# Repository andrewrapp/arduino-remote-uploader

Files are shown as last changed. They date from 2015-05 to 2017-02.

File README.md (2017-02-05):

# arduino-remote-uploader

The goal of this project is provide over-the-air (OTA) upload of Arduino sketches to a remote Arduino. There is support for XBee (Series 1 and 2), Wifi (ESP8266), and Nordic nRF24L01+. This is accomplished by programming one Arduino with another. The circuit is conceptually very simple:

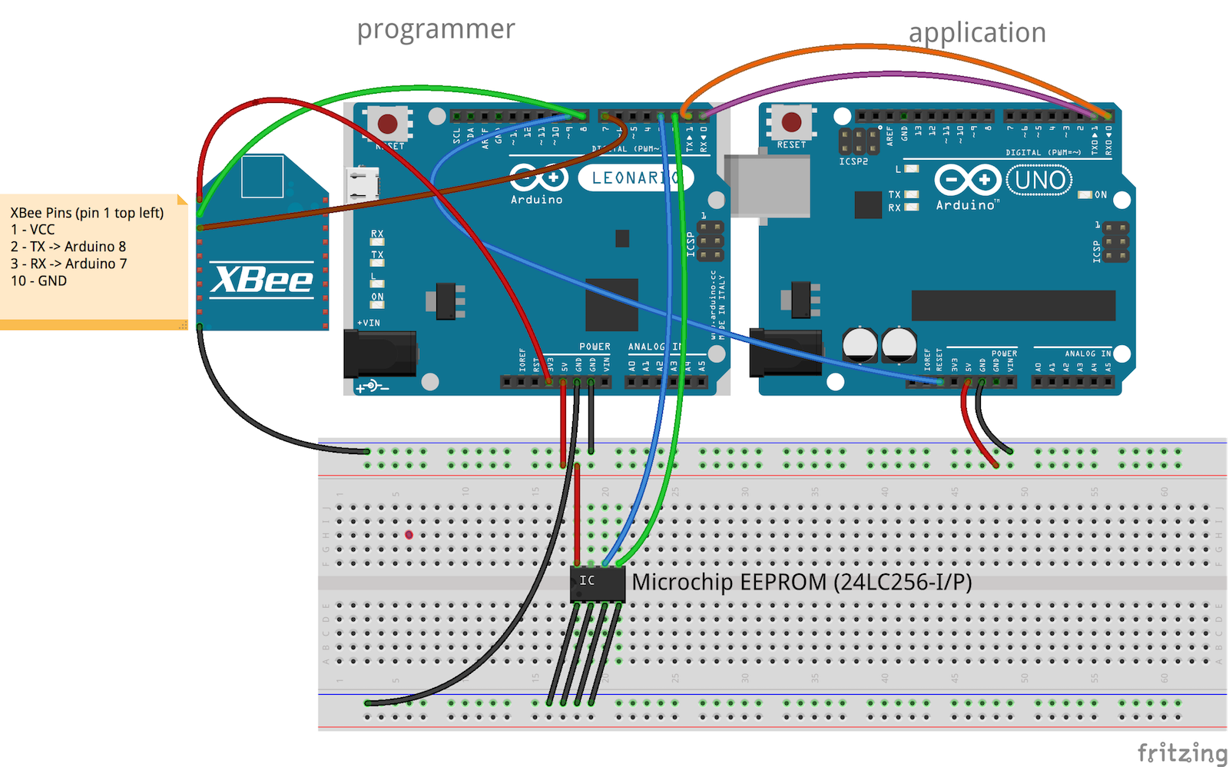
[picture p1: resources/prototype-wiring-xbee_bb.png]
xbee prototype


One Arduino receives firmware packets from a wireless device (XBee in this case) and writes to EEPROM. Then, once it receives the entire sketch it flashes the firmware on the other Arduino. There are other tricks for remote firmware programming but nearly all involve unfortunate tradeoffs. This solution is fault tolerant, in that it checksums every firmware page (packet), acks and retries dropped packets and only flashes when a complete firmware image has been written to EEPROM. You can unplug the remote during programming, then plug back in and it will resume and flash successfully.

It's also quite cost-effective: the Microchip EEPROM costs $1. Arduino Pros can be found online for about $3 each. Nordic radios can be found for about $1 online.

Here's a prototype I built to control my garage door. A Modern Device RBBB performs the programming while the app runs on a Arduino Pro. I'm using an Arduino XBee shield just for the XBee socket and 3.3V conversion. 

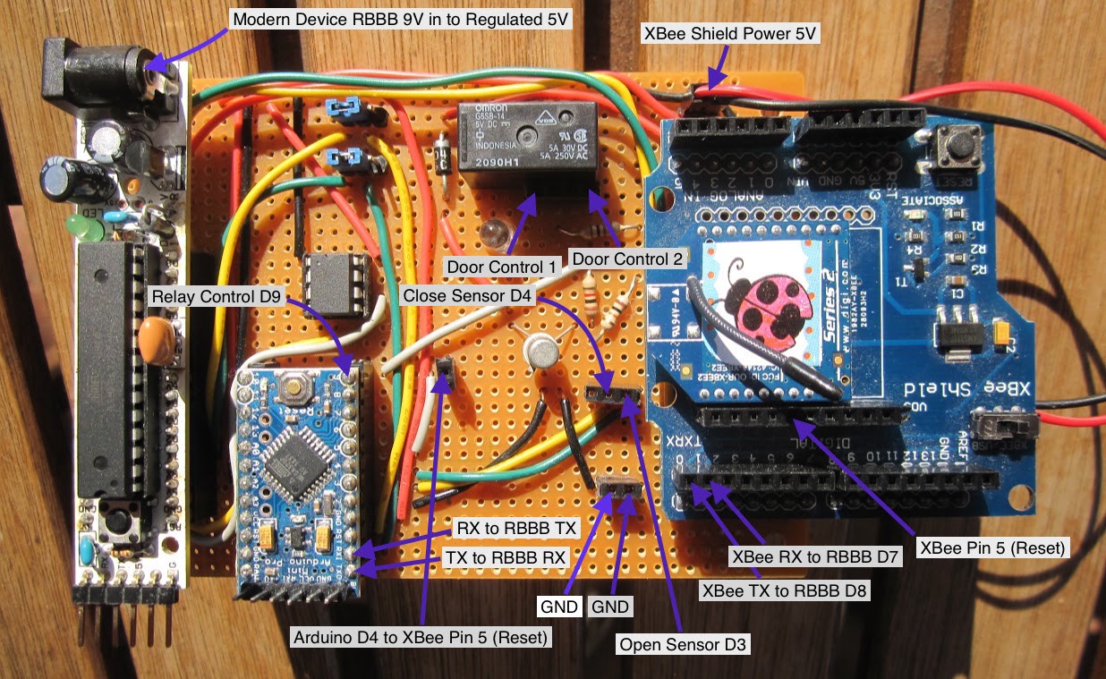
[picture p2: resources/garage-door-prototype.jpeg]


The client is a simple command-line app:

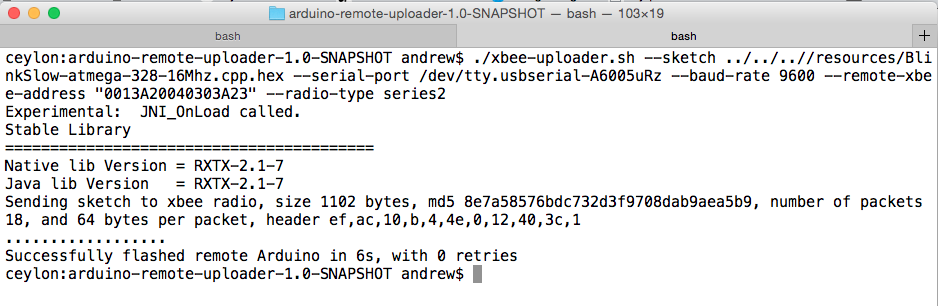
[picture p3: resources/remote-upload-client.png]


Here's a <a href="https://youtu.be/Vqg-zZniQU0" target="_blank">screenshare</a> of an upload in action.

Version [0.1](https://search.maven.org/#search%7Cga%7C1%7Ca%3A%22arduino-remote-uploader%22) is in Maven Central

<!--<video src="https://github.com/andrewrapp/arduino-remote-uploader/blob/master/resources/remote-flash-screen-recording.mov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" controls autoplay></video>-->

I've written about the project in detail on Medium https://medium.com/@nowir3s/arduino-remote-uploader-aa61e4d620b1

Demo

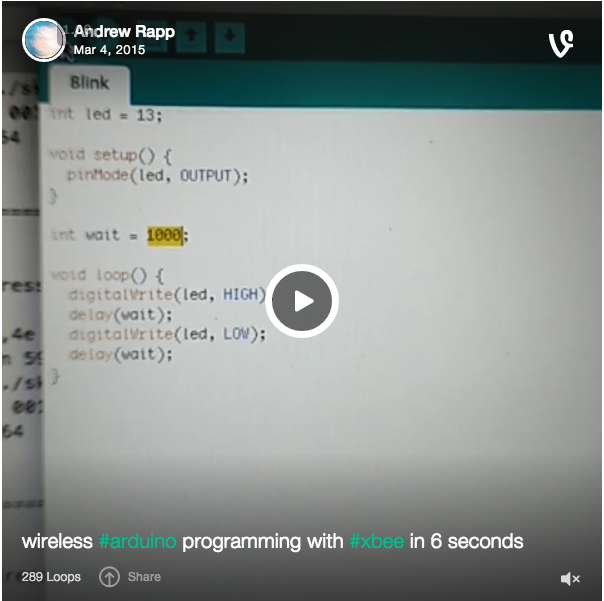
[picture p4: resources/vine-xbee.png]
vine


The remote Arduino starts with a sketch that blinks fast. Then, I change the sketch to blink slow, compile and flash the sketch on the remote Arduino, via XBee. The command completes and indicates that the flash was successful. And lastly we see the Arduino is running the new sketch and blinking slowly. So there it is: over-the-air Arduino programming via XBee in six seconds!

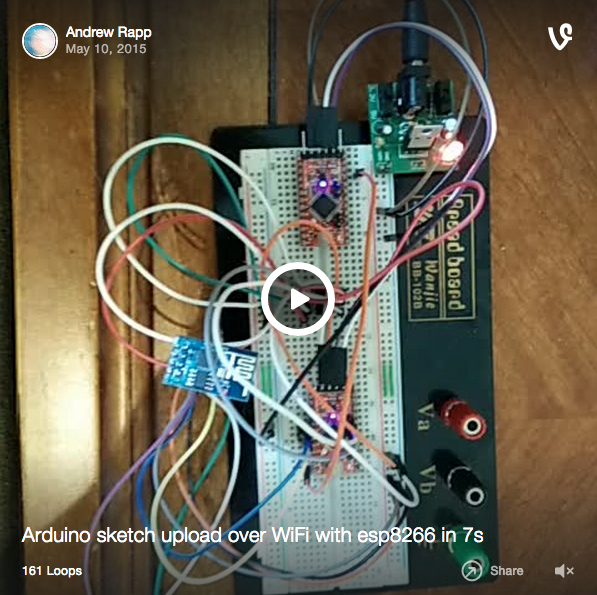
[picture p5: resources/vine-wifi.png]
vine


Here's the same thing but over wifi with a esp8266 and 3.3V Arduino Pros at 8Mhz.

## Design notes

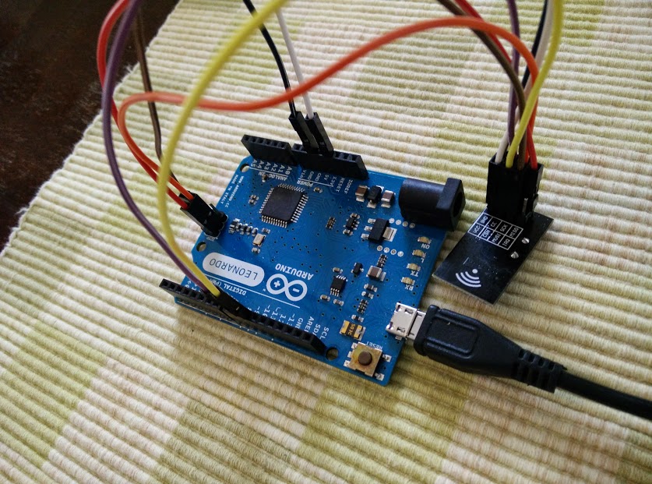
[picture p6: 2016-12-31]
resources/nordic-arduino.jpg

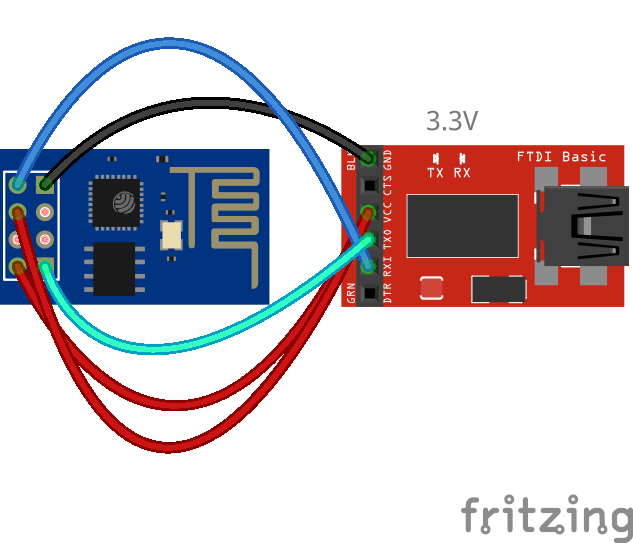
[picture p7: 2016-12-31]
resources/esp8266-ftdi_bb.png

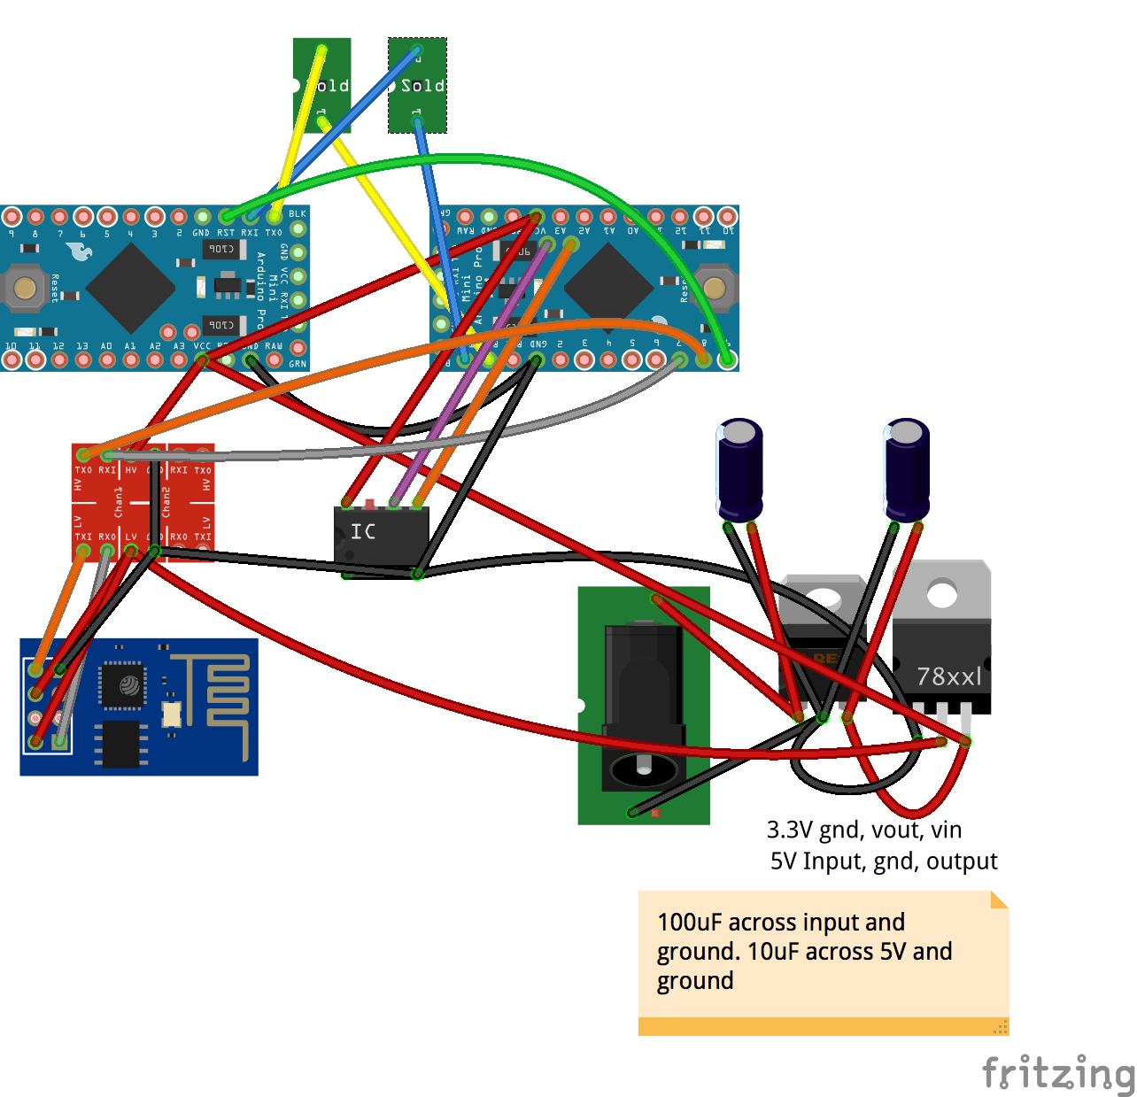
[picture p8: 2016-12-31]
resources/esp-perfboard_bb.png

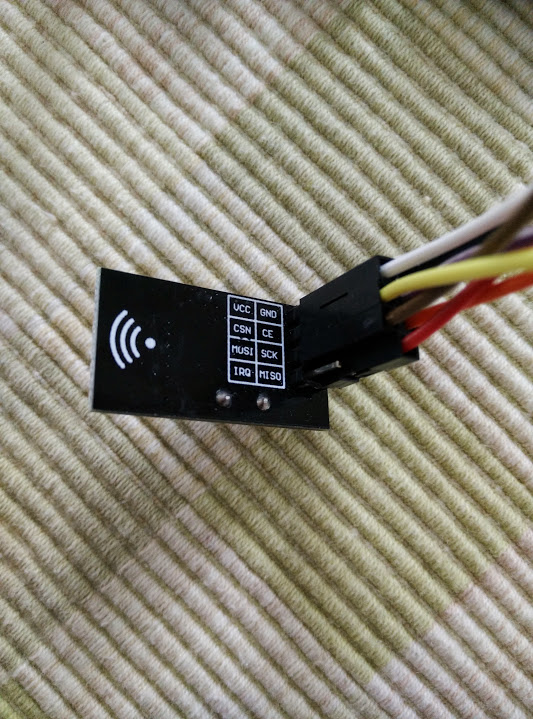
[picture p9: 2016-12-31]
resources/nordic-pins.jpg

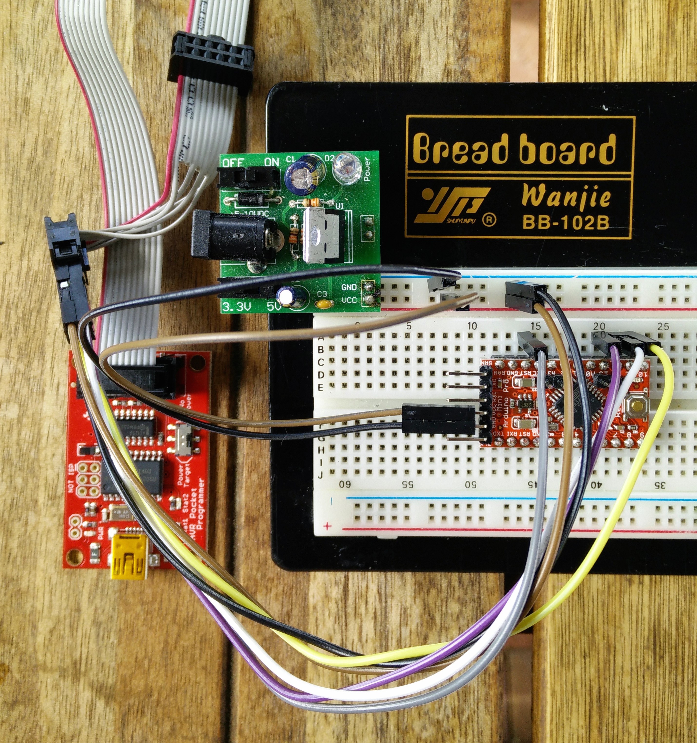
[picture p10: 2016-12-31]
resources/pocketprogrammer-arduino-pro.jpg

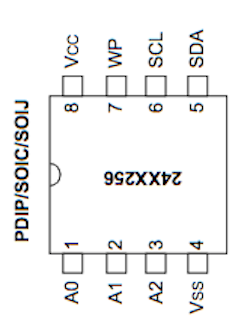
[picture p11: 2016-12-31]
resources/microchip-eeprom-pins.png

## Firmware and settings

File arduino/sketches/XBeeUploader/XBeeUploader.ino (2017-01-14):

/**
 * Copyright (c) 2015 Andrew Rapp. All rights reserved.
 *
 * This file is part of arduino-sketcher
 *
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
 * You should have received a copy of the GNU General Public License
 * along with arduino-sketcher.  If not, see <http://www.gnu.org/licenses/>.
 */
 
#include <XBee.h>
#include <SoftwareSerial.h>
#include <extEEPROM.h>
#include <Wire.h>
#include <RemoteUploader.h>

// NOTE: Leonardo seems to have no problem powering the xbee ~50ma and and a Diecimila

// If the xbee is only used for firmware updates and the app arduino doesn't use it this can be false
#define PROXY_SERIAL true
#define XBEE_BAUD_RATE 9600
#define USBDEBUG false

#define SERIES1 1
#define SERIES2 2

// TODO send with start header
#define ACK_TIMEOUT 1000

// these can be swapped to any other free digital pins
#define XBEE_SOFTSERIAL_RX_PIN 7
#define XBEE_SOFTSERIAL_TX_PIN 8
#define RESET_PIN 9

// set a dummy address. all tx will be sent to the sender via getRemoteAddress
const uint32_t COORD_MSB_ADDRESS = 0;
const uint32_t COORD_LSB_ADDRESS = 0;

XBee xbee = XBee();
XBeeResponse response = XBeeResponse();
// series 1 rx objects
Rx64Response rx1 = Rx64Response();
// series 2
ZBRxResponse rx2 = ZBRxResponse();

// format magic bytes, status, id1, id2
uint8_t xbeeTxPayload[] = { MAGIC_BYTE1, MAGIC_BYTE2, 0, 0, 0 };

// TODO use ifdef to either include series 1 or 2 but not both

// Coordinator Gateway
XBeeAddress64 addr64 = XBeeAddress64(COORD_MSB_ADDRESS, COORD_LSB_ADDRESS);
// series 1
Tx64Request tx1 = Tx64Request(addr64, xbeeTxPayload, sizeof(xbeeTxPayload));
// series 2
ZBTxRequest tx2 = ZBTxRequest(addr64, xbeeTxPayload, sizeof(xbeeTxPayload));

// status response
// series 1
TxStatusResponse txStatus1 = TxStatusResponse();
// series 2
ZBTxStatusResponse txStatus2 = ZBTxStatusResponse();

//Since Arduino 1.0 we have the superior softserial implementation: NewSoftSerial
// Remember to connect all devices to a common Ground: XBee, Arduino and USB-Serial device
SoftwareSerial nss(XBEE_SOFTSERIAL_TX_PIN, XBEE_SOFTSERIAL_RX_PIN); // RX, TX

RemoteUploader remoteUploader = RemoteUploader();

extEEPROM eeprom = extEEPROM(kbits_256, 1, 64);

// keep track radio type: series 1 or 2
uint8_t series = 0;

Stream* getXBeeSerial() {
  return &nss;  
}

void setup() {
  // for atmega328/168 use &Serial
  // do not set baud rate as the uploader does this
  remoteUploader.setup(&Serial, &eeprom, RESET_PIN);  
  // for Leonardo must use Serial1
  //remoteUploader.setup(&Serial1, &eeprom, RESET_PIN);
  //configure debug if an additional Serial port is available. Use Serial with Leonardo
  // for some reason I can only program with a Leonardo when the serial console is open, even if I'm not using debug!
  //remoteUploader.setDebugSerial(&Serial);

  // TODO if setup_success != OK send error programming attempt
  // we only have one Serial port (UART) so need nss for XBee
  
  nss.begin(XBEE_BAUD_RATE);  
  xbee.setSerial(nss);

  // Start the serial port for the xbee baud rate when proxying
  if (PROXY_SERIAL) {
    // we flashed so reset to xbee baud rate for proxying
    remoteUploader.getProgrammerSerial()->begin(XBEE_BAUD_RATE);              
  }
            
  #if (USBDEBUG || NSSDEBUG) 
    remoteUploader.getDebugSerial()->println("Ready");
  #endif
}

// TODO move to library.. tell library of the proxySerial port
void handleProxy() {
  // don't need to test in_prog. if in prog we are just collecting packets so can keep relaying. when flashing, it's blocking so will never get here
  // forward packets from target out the radio
  if (PROXY_SERIAL) {
    while (remoteUploader.getProgrammerSerial()->available() > 0) {
      int b = remoteUploader.getProgrammerSerial()->read();
      getXBeeSerial()->write(b); 
    }      
  }
}

// TODO send version
int sendReply(uint8_t status, uint16_t id) {
  xbeeTxPayload[0] = MAGIC_BYTE1;
  xbeeTxPayload[1] = MAGIC_BYTE2;
  xbeeTxPayload[2] = status;
  xbeeTxPayload[3] = (id >> 8) & 0xff;
  xbeeTxPayload[4] = id & 0xff;
  
  // TODO send with magic packet host can differentiate between relayed packets and programming ACKS
  if (series == SERIES1) {
    xbee.send(tx1);        
  } else if (series == SERIES2) {
    // send reply to sender xbee
    tx2.setAddress64(rx2.getRemoteAddress64());
    xbee.send(tx2);    
  }
  
  // after send a tx request, we expect a status response
  // wait up to half second for the status response
  if (xbee.readPacket(ACK_TIMEOUT)) {    
    if (xbee.getResponse().getApiId() == ZB_TX_STATUS_RESPONSE) {
      // series 2
      xbee.getResponse().getZBTxStatusResponse(txStatus2);

      // get the delivery status, the fifth byte
      if (txStatus2.isSuccess()) {
        return 0;
      } else {
        #if (USBDEBUG || NSSDEBUG) 
          remoteUploader.getDebugSerial()->println("TX fail");
        #endif  
      }
    } else if (xbee.getResponse().getApiId() == TX_STATUS_RESPONSE) {
      // series 1
      xbee.getResponse().getTxStatusResponse(txStatus1);
        
      if (txStatus1.getStatus() == SUCCESS) {
        return 0;
      } else {
        #if (USBDEBUG || NSSDEBUG) 
          remoteUploader.getDebugSerial()->println("TX fail");
        #endif      
      }  
    }   
  } else if (xbee.getResponse().isError()) {
    #if (USBDEBUG || NSSDEBUG)
      // starting to see lots of these. check wire connections are secure
      remoteUploader.getDebugSerial()->print("TX error:");  
      remoteUploader.getDebugSerial()->print(xbee.getResponse().getErrorCode());
    #endif
  } else {
    #if (USBDEBUG || NSSDEBUG) 
      remoteUploader.getDebugSerial()->println("TX timeout");
    #endif  
  } 
  
  return -1;
}


// borrowed from xbee api. send bytes with proper escaping
void send_xbee_packet(uint8_t b, bool escape) {
  if (escape && (b == START_BYTE || b == ESCAPE || b == XON || b == XOFF)) {
    remoteUploader.getProgrammerSerial()->write(ESCAPE);    
    remoteUploader.getProgrammerSerial()->write(b ^ 0x20);
  } else {
    remoteUploader.getProgrammerSerial()->write(b);
  }
  
  remoteUploader.getProgrammerSerial()->flush();
}

void forwardPacket() {
  // not programming packet, so proxy all xbee traffic to Arduino
  // prob cleaner way to do this if I think about it some more
  
  #if (USBDEBUG || NSSDEBUG) 
    remoteUploader.getDebugSerial()->println("Forwarding packet");    
  #endif
        
  // send start byte, length, api, then frame data + checksum
  send_xbee_packet(START_BYTE, false);
  send_xbee_packet(xbee.getResponse().getMsbLength(), true);
  send_xbee_packet(xbee.getResponse().getLsbLength(), true);        
  send_xbee_packet(xbee.getResponse().getApiId(), true);

  uint8_t* frameData = xbee.getResponse().getFrameData();
   
  for (int i = 0; i < xbee.getResponse().getFrameDataLength(); i++) {
    send_xbee_packet(*(frameData + i), true);
  }
   
   send_xbee_packet(xbee.getResponse().getChecksum(), true);  
}

// TODO ack needs to send the id (packet #) otherwise we may be getting a different ack, right?

void loop() {        
  xbee.readPacket();
  
  if (xbee.getResponse().isAvailable()) {  
    // if not programming packet, relay exact bytes to the arduino. need to figure out how to get from library
    // NOTE the target sketch should ignore any programming packets it receives as that is an indication of a failed programming attempt
          
      uint8_t *packet = NULL;
      uint8_t length;
      bool progPacket = false;
      
      if (xbee.getResponse().getApiId() == ZB_RX_RESPONSE) {  
        // series 2    
        series = SERIES2;
        // now fill our zb rx class
        xbee.getResponse().getZBRxResponse(rx2);
        
        // pointer of data position in response
        packet = xbee.getResponse().getFrameData() + rx2.getDataOffset();
        length = rx2.getDataLength();
      } else if (xbee.getResponse().getApiId() == RX_64_RESPONSE) {
        // series 1
        series = SERIES1;        
        xbee.getResponse().getRx64Response(rx1);      

        // pointer of data position in response
        packet = xbee.getResponse().getFrameData() + rx1.getDataOffset();        
        length = rx1.getDataLength();
      } else {
        // unexpected packet.. ignore
      }

      if (packet != NULL) {
        if (length > 4 && remoteUploader.isProgrammingPacket(packet, length)) {
          progPacket = true;
          
          // send the packet array, length to be processed
          int response = remoteUploader.process(packet);
              
          // do reset in library
          if (response != OK) {
            remoteUploader.reset();
          }

          sendReply(response, remoteUploader.getPacketId(packet));          
          
          if (remoteUploader.isFlashPacket(packet)) {
            if (PROXY_SERIAL) {
              // we flashed so reset to xbee baud rate for proxying
              remoteUploader.getProgrammerSerial()->begin(XBEE_BAUD_RATE);              
            }
          }          
        }     
      }
      
      if (!progPacket && PROXY_SERIAL) {
        // not a programming packet. forward along
        forwardPacket();                           
      }
  } else if (xbee.getResponse().isError()) {
    #if (USBDEBUG || NSSDEBUG) 
      remoteUploader.getDebugSerial()->print("RX error: ");
      remoteUploader.getDebugSerial()->println(xbee.getResponse().getErrorCode(), DEC);
    #endif  
  }  
  
  handleProxy();
}

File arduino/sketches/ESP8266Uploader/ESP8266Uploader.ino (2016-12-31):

/**
 * Copyright (c) 2015 Andrew Rapp. All rights reserved.
 *
 * This file is part of arduino-sketcher
 *
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
 * You should have received a copy of the GNU General Public License
 * along with arduino-sketcher.  If not, see <http://www.gnu.org/licenses/>.
 */

#include <extEEPROM.h>
// eeprom requires i2c
#include <Wire.h>
#include <SPI.h>

#include <RemoteUploader.h>
#include <Esp8266.h>
#include <SoftwareSerial.h>

// NOTE: only some pins support softserial RX on Leonard and Mega boards
#define ESP_RX 8
#define ESP_TX 7

#define ESP_PACKET_SIZE 32

#define REPLY_SIZE 5
#define RESET_PIN 9

#define LED_PIN 13

// TODO send ip address to server on boot for discovery. Otherwise we'd have to guess or query the router's dhcp table (not always possible)

// FIXME client is getting socket timeouts. add ping method to restart if loses ip address
// TODO proxy when not in programming mode

// When true this only tests the ESP communication, does not use the remote uploader library.
// This is useful to debug any issues with ESP using the serial port before throwing flashing into the mix
#define COMMUNICATION_TEST false

SoftwareSerial espSerial(ESP_RX, ESP_TX);
Esp8266 esp8266 = Esp8266();

// this is arbitrary, any port will do
int serverPort = 1111;

uint8_t replyPayload[] = { MAGIC_BYTE1, MAGIC_BYTE2, 0, 0, 0 };
uint8_t packet[ESP_PACKET_SIZE];

RemoteUploader remoteUploader = RemoteUploader();
extEEPROM eeprom = extEEPROM(kbits_256, 1, 64);

/* 6/24 - at times getting ERROR or just an OK on listing networks (with FTDI). Also will not join a network. Could it be the access point rejecting?
AT+CWLAP

ERROR

AT+CWLAP

OK
*/

// 6/25 esp passes communication test on perfboard with DEBUG enabled, but once debug is set to false it gets an IPD error and sketch resets the radio
// setup works fine. Could be the voltage divider can't handle the speed without debug slowdown
// try leonardo with debug
// try 3.3V Arduinos

void setup() {
  
  pinMode(LED_PIN, OUTPUT);   
    
  if (COMMUNICATION_TEST == false) {
    // for Leonardo use &Serial1
    // for atmega328/168 use &Serial
    if (remoteUploader.setup(&Serial, &eeprom, RESET_PIN) != SUCCESS) {
      // eeprom fail
      // optional error reporting
      blink(2, 2000);
    }
    
    //configure debug if an additional Serial port is available (e.g. Leonardo)
    //remoteUploader.setDebugSerial(&Serial);    
    
    // NOTE: Only if you are using a 3.3V/8Mhz I highly recommend running Optiboot at 57.6K instead of 115.2K with 8Mhz Arduinos. This requires the 5V/16Mzh optiboot bootloader
    //remoteUploader.setBaudRate(OPTIBOOT_8MHZ_BAUD_RATE);
  }

  // delay is recommended since if esp8266 is booting it will spew the boot garbage for about 3 seconds. any setup commands would fail
  delay(3000);  
  
  espSerial.begin(9600);
  // configure esp to use softserial
  esp8266.setEspSerial(&espSerial);  
  
  Serial.begin(9600); while(!Serial); // UART serial debug
  
  if (COMMUNICATION_TEST) {
    // make sure esp library has #DEBUG enabled before uncommenting
    //esp8266.setDebugSerial(&Serial);    
  }
  
  // set the packet array for receiving data
  esp8266.setDataByteArray(packet, ESP_PACKET_SIZE);

  // Perform first time esp configuration to connect to AP. Only need to run once
//  if (esp8266.configure("ssid","password") != SUCCESS) {
//    if (COMMUNICATION_TEST) {
//      Serial.println("Configure failed");
//    }
//    
//    blink(5, 1000);
//    for (;;) {}
//  }

  while (!esp8266.configureServer(serverPort)) {      
    blink(4, 1000);       
    
    if (COMMUNICATION_TEST) {
      Serial.println("Failed to configure server");
    }
  }
  
  // indicate successful setup
  blink(1, 50);  
}

void blink(int times, int wait) {
  for (int i = 0; i < times; i++) {
    digitalWrite(LED_PIN, HIGH);
    delay(wait);
    digitalWrite(LED_PIN, LOW);
    
    if (i < times - 1) {
      delay(wait);      
    }
  }
}

// send reply to host
int sendReply(uint8_t status, uint16_t id) {
  replyPayload[0] = MAGIC_BYTE1;
  replyPayload[1] = MAGIC_BYTE2;
  replyPayload[2] = status;
  replyPayload[3] = (id >> 8) & 0xff;
  replyPayload[4] = id & 0xff;
    
  // send reply
  if (esp8266.send(esp8266.getChannel(), replyPayload, REPLY_SIZE) != SUCCESS) {
    if (COMMUNICATION_TEST) {
      Serial.println("Failed to send reply");
    }
  }
}

void handleProgramming() {
  // send the packet array, length to be processed
  int response;
  
  if (COMMUNICATION_TEST) {
    // send back a success
    response = OK;
  } else {
    response = remoteUploader.process(packet);                    
  
    // TODO do reset in library
    if (response != OK) {
      remoteUploader.reset();
    }          
  }
  
  sendReply(response, remoteUploader.getPacketId(packet));          
    
  if (remoteUploader.isFlashPacket(packet)) {
    // flash is complete
  }
}

void loop() {
  if (esp8266.readSerial()) { 
    if (esp8266.isData()) {
      // got data
      if (esp8266.getDataLength() > 4 && remoteUploader.isProgrammingPacket(packet, esp8266.getDataLength())) {
        handleProgramming();
      } else {
        // TODO not programming, forward
      }
    } else if (esp8266.isConnect()) {
        if (remoteUploader.inProgrammingMode() == false) {
          // TODO forward
        }
    } else if (esp8266.isDisconnect()) {
        if (remoteUploader.inProgrammingMode() == false) {
          // TODO forward
        }
    } 
  } else if (esp8266.isError()) {
    blink(3, 50);
    
    if (COMMUNICATION_TEST) {
      Serial.print("Failed on command ");
      Serial.print(esp8266.getLastCommand());
      Serial.print(" with error ");
      Serial.println(esp8266.getLastResult());          
    } else {
      // attempt to send error to client. may not work 
    } 
    
    if (esp8266.getLastCommand() == UNKNOWN_COMMAND) {
      if (COMMUNICATION_TEST) {
        Serial.print("Resetting");
      }
      
      // restart
      // assume the worst and reset
      esp8266.restartEsp8266();
      // need to apply server config which is lost on restart
      esp8266.configureServer(serverPort);
    }
  } else {
   // no data 
  }
}

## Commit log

2015-02-08 divide address by 2 and send little endian, which bootloader seems to expect. Sketch current broken
2015-02-13 First cut of XBee transport for remote programming
2015-02-14 EEPROMSketcher receives sketch over serial, writes to eeprom, then reads from eeprom and successfully programs arduino
2015-02-15 Screwed up resetPin. Fail on delivery failure
2015-02-15 ugh, forgot to add the eeprom offset so last page was missing 16 bytes. Fixed and successfully programmed my diecimila over xbeegit add arduino/ java-loader/src/
2015-02-15 Reset state on start packet. Improved debug output: Ready! *Received start xbee packet *********************************** Bouncing the Arduino Talking to Optiboot Flashing from eeprom... Flashed in 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
    Successfully flashed remote Arduino in 10596ms. Got to take a break, familiy is getting irritated with me
2015-02-15 Added proxy to relay serial. disable debug serial
2015-02-16 XBee packet relay from application is working. forward to application needs work
2015-02-16 Verified xbee sketcher can forward packets to/from application arduino running xbee sketch
2015-02-22 Add #if to compile for 328/non-leonardo boards w/o usb serial
2015-02-28 Added preprocessor directives for XBeeSketcher. Failing on flash currently
2015-03-01 Added additional codes to send to xbee on failures. Working on arduino pros
2015-03-01 Add command line parser and maven assembly
2015-03-07 factoring xbee out of flash/eeprom functions, add java interrupt
2015-03-08 Changed nordic pins to free up reset pin
2015-03-08 Nordic sketcher. working up to flash start and sync error: psize 44E,cur addr 45E
    [NordicSerial2SPI.ino, eeprom_flasher.h]
2015-03-08 Upload via Nordic working now. Lots of error handling to deal with
    [eeprom_flasher.h]
2015-03-09 Modify eeprom flasher to reset on prog start when in prog mode. aligning picture frames
    [eeprom_flasher.h]
2015-03-09 Nothing wrong with preprocessor directives. getting Unexpected response -24320 on tx failures
    [NordicSerial2SPI.ino]
2015-03-12 Created RemoteUploader Arduino C++ library
2015-03-13 Fix bug with unexpected error code reporting as success
    [NordicSerial2SPI.ino]
2015-03-13 Added arduino and ack timeouts to uploaders
2015-03-14 Implemented retries for NordicSerial2SPI. Fix bug with return code
    [NordicSerial2SPI.ino]
2015-03-15 Add reply id to all ack packets to resolve multiple retry issue with xbee
    [NordicSerial2SPI.ino]
2015-03-15 Added ack id to nordic sketch. Switched xbee pins to 7.8 to allow both XBee and Nordic to be connected on same board to make dev easier
2015-04-10 Add critical 100ms delay between socket writes in java to prevent dropped packets
2015-04-11 Update to only reset every 3 hours.. may not even be necessar now. Close current connection and shutdown server port prior to reset
    [ESP8266.ino]
2015-04-11 First cut of wifi uploader. not functioning
2015-04-11 Increase read timeout from 1s to 5s to prevent timeout errors
    [ESP8266.ino]
2015-04-14 Much better..around 1% error
    [ESP8266.ino]
2015-05-11 Fix silly scope bug with XBee packet assignment
    [XBeeUploader.ino]
2015-06-01 Fix bug with reset pin on Arduino startup. Needs to be in pin mode INPUT except during bounce
    [Esp8266SerialProxy.ino, XBeeUploader.ino]
2015-10-08 Added vine for wifi arduino flashing
2016-12-30 No longer require the coordinate xbee address hardcoded in sketch -- simply send reply to sender's address (getRemoteAddress64); Set proxy serial to true; resolve serial port pin confusion
    [XBeeUploader.ino]
2016-12-31 Simple proxy sketch for esp8266 debugging. Proxies all traffic to/from Arduino
2016-12-31 Added fritzing files and prototype photos
    [5v-3.3v-power-circuit.fzz, esp-perfboard.fzz, esp8266-arduino-voltage-divider.fzz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]
2017-01-01 fix proxying issue: initialize serial port to xbee baud rate on startup or proxying fails
    [XBeeUploader.ino]
2017-01-01 Support remote programming via xbee socket server. Added tx ack timeout to cmd args
2017-01-01 rename and resize prototype fzz/png
    [prototype-wiring-xbee.fzz]
2017-01-08 Added maven central publishing config. now dep on xbee-api 0.9.2 with socket client. Dropped dep on xbee-socket
2017-02-05 Add photo of garage door prototype

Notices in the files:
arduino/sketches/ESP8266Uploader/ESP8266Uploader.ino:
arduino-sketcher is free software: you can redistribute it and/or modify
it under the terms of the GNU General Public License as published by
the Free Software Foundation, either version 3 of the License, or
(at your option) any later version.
